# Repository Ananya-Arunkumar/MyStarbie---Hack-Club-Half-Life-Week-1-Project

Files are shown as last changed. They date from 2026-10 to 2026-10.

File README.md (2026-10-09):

**Starbie**

Starbie is a tiny desk buddy built using a Seeed XIAO ESP32-C3, an OLED display, and motion and temperature sensors.



PCB Editor View



3D view

**Features**
* Animated digital pet on a 0.96-inch OLED display
* Motion-controlled radial menu using an MPU6050 accelerometer
* Pet stats for joy, energy, and fullness
* Temperature and humidity readings using a DHT11 sensor
* Two buttons for interacting with the pet

**Hardware**
* Seeed XIAO ESP32-C3
* 0.96-inch SSD1306 OLED display
* MPU6050 accelerometer and gyroscope module (lets the thing know it's moving)
* DHT11 temperature and humidity sensor
* Two push buttons
* Starbie PCB

See BOM.csv for the bill of materials and PCB folder for the PCB design files.

**Software**
The PCB is designed using KiCad. The firmware is written for the Arduino IDE. (Refer firmware Folder)

**Building**
1. Gather the components listed in the bill of materials.
2. Assemble the circuit according to the schematic and wiring instructions.
3. Open the Starbie Arduino sketch in the Arduino IDE.
4. Install the required libraries.
5. Select the Seeed XIAO ESP32-C3 as the board.
6. Upload the sketch to the board.

Refer to the project guide for detailed assembly and setup instructions.

Project Files
Firmware/ — MyStarbie.ino
PCB/ — PCB layout, schematic, and KiCad project files
BOM.csv — Bill of materials

**Credits**
Starbie is based on the original project by SharKingStudios and Hack Club. Please refer to the original project repository and its license for attribution and reuse requirements.

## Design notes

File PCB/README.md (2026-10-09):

Starbie PCB Design Files

All of this is made through KiCad. Please download the necessary software and download the files for custom footprints and symbols.

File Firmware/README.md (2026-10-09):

**FIRMWARE**

The firmware is written for the Arduino IDE. Download the latest version of the Arduino IDE.

Below are some required libraries that I downloaded. You have to download these libraries in order for the firmware to work for this.
Required libraries:
Adafruit GFX Library
Adafruit SSD1306
Adafruit MPU6050
DHT sensor library

**Directions to install:**
1. Click _File_ --> _Preferences_ --> add the code below into the _Additional Board Managers URL_
* https://espressif.github.io/arduino-esp32/package_esp32_index.json
2. Select _Tools_ --> _Board_ --> _Board Manager_ --> search and download esp32 by Espressif Systems
3. Select _Tools_ --> _Board_ --> _esp32_ --> _XIAO_ESP32C3_ --> select the board's port under _Tools_ --> _Port_
4. Download the libraries above one by one (Click download all when asked about dependencies)
5. Open the Starbie.ino file and click Upload in the IDE

Under beginner settings is where I made my customizations. I changed the pet's starting stats, changed the bitmap pet, replaced the pet function on the radial menu with 'Shower', and gave it a star trail!

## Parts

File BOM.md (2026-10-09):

Starbie Kit - Provided by Hack Club

PCB - 9.90 + 9.33 shipping (JLCPCB)

Estimated total - $19.23

**Keep in mind, there is a BOM on the original Starbie repo which rounds to around 24.95 per kit but it is more expensive to buy that on your own since most of its components come in packs which cost more than listed**

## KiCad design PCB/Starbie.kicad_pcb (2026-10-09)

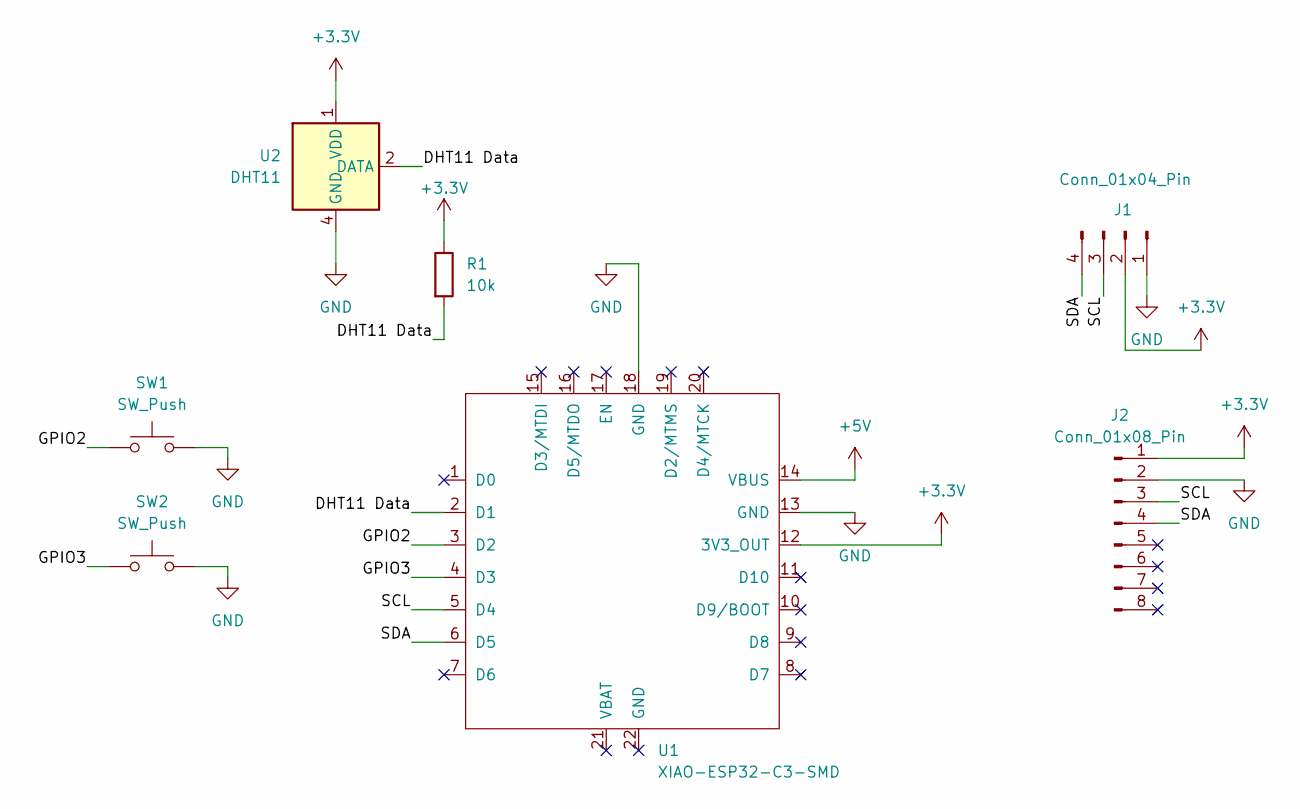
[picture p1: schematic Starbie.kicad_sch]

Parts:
J1: Conn_01x04_Pin; Display_128x64_096_I2C
J2: Conn_01x08_Pin; PinHeader_1x08_P2.54mm_Vertical
R1: 10k; R_Axial_DIN0204_L3.6mm_D1.6mm_P7.62mm_Horizontal
SW1, SW2: SW_Push; SW_Cherry_MX_1.00u_PCB
U1: XIAO-ESP32-C3-SMD
U2: DHT11; Aosong_DHT11_5.5x12.0_P2.54mm

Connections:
+3.3V: J1.2, J2.1, R1.1, U1.12 (3V3_OUT), U2.1 (VDD)
+5V: U1.14 (VBUS)
/DHT11 Data: R1.2, U1.2 (D1), U2.2 (DATA)
/GPIO2: SW1.1, U1.3 (D2)
/GPIO3: SW2.1, U1.4 (D3)
/SCL: J1.3, J2.3, U1.5 (D4)
/SDA: J1.4, J2.4, U1.6 (D5)
GND: J1.1, J2.2, SW1.2, SW2.2, U1.13 (GND), U1.18 (GND), U2.4 (GND)

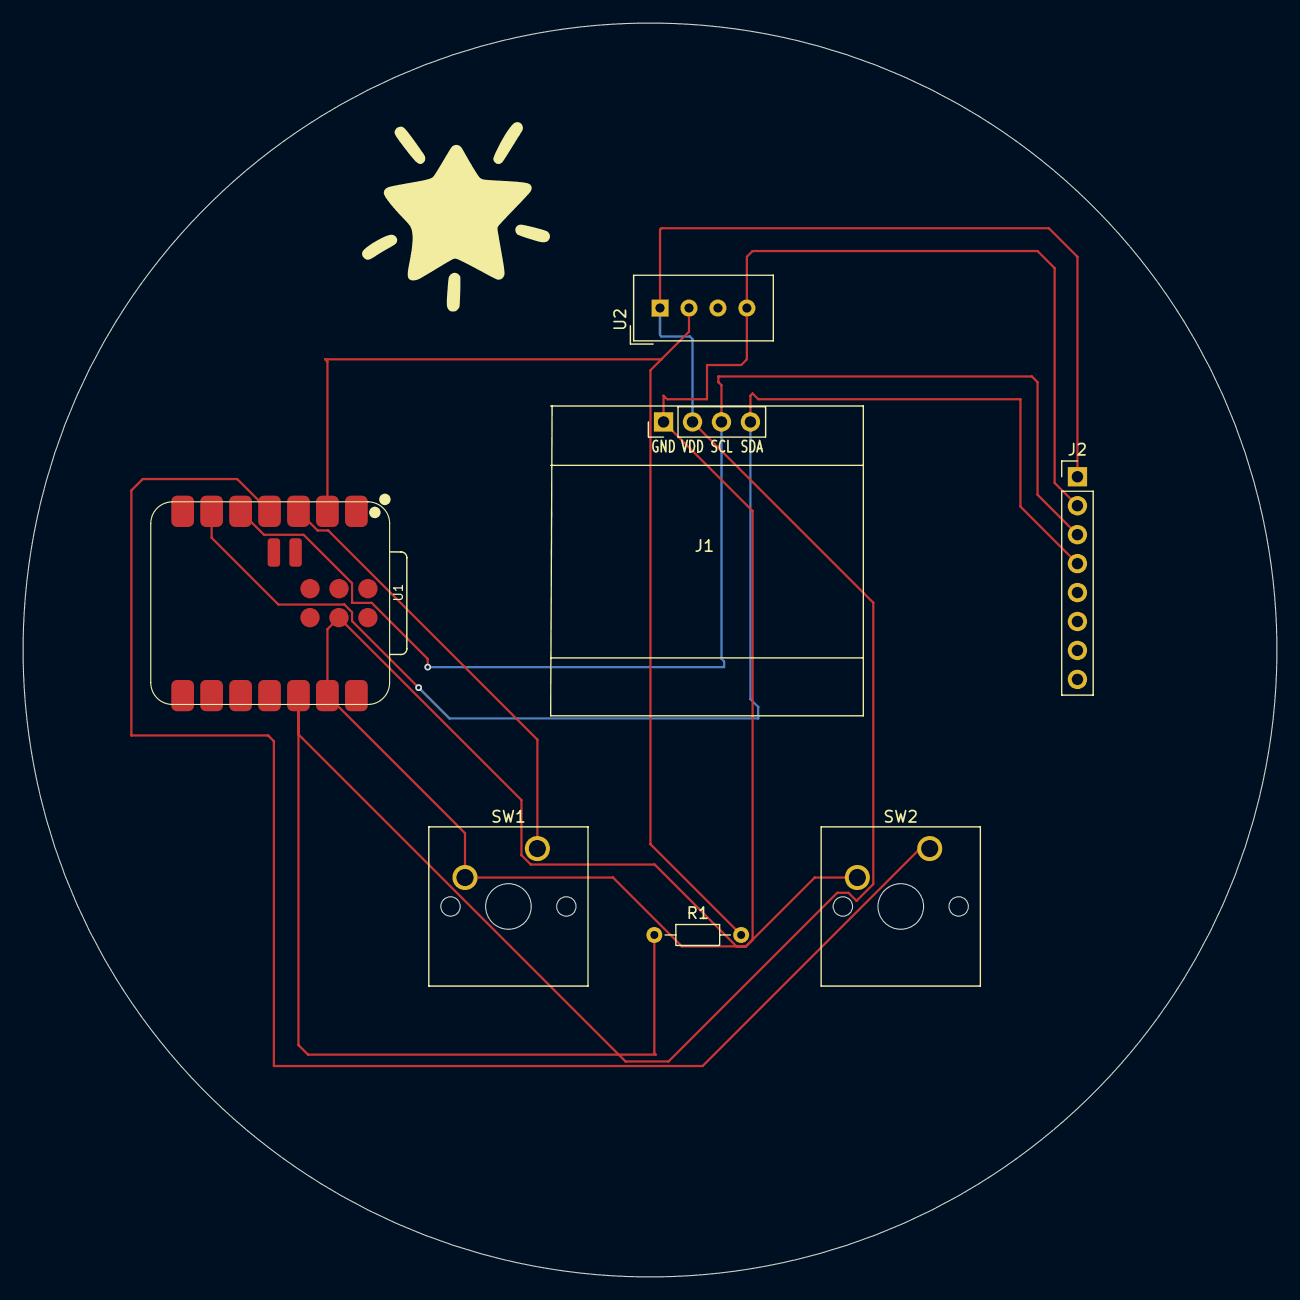
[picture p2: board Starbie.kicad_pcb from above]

Board: 2 copper layers, 110.0 x 110.0 mm, 7 parts (0 on the bottom side), 7 nets.

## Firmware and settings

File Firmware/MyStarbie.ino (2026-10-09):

/*
  Starbie: a tiny motion-controlled digital pet

  This is intentionally one file. Open this .ino file in Arduino IDE, edit
  the BEGINNER SETTINGS section, and upload it to a Seeed XIAO ESP32-C3.

  Install these libraries with Sketch > Include Library > Manage Libraries:
    - Adafruit GFX Library
    - Adafruit SSD1306
    - Adafruit MPU6050
    - DHT sensor library
  Arduino IDE will offer to install their dependencies too. Click Install All.
*/

#include <Wire.h>
#include <Adafruit_GFX.h>
#include <Adafruit_SSD1306.h>
#include <Adafruit_MPU6050.h>
#include <DHT.h>
#include <Preferences.h>
#include <math.h>

// =========================== BEGINNER SETTINGS ===========================
// Everything most builders will want to customize is in this one section.

// --- Your board's pins ----------------------------------------------------
// These are ESP32-C3 GPIO numbers, with the XIAO pin labels beside them.
const int I2C_SDA_PIN = 6;       // XIAO D4: OLED + MPU6050 SDA
const int I2C_SCL_PIN = 7;       // XIAO D5: OLED + MPU6050 SCL
const int DHT_PIN = 3;           // XIAO D1: DHT11 data
const int BUTTON_ONE_PIN = 4;    // XIAO D2: opens/confirms the radial menu
const int BUTTON_TWO_PIN = 5;    // XIAO D3: shows/hides stats

// Set this to false if your submission does not have a DHT11.
const bool USE_DHT11 = true;

// Most parts use these addresses. Only change them if an I2C scanner says
// your part is different (common OLED alternative: 0x3D).
const uint8_t OLED_ADDRESS = 0x3C;
const uint8_t MPU6050_ADDRESS = 0x68;

// --- Starting stats -------------------------------------------------------
// Stats are 0 to 100. They only change when you select an action or shake
// Starbie; nothing slowly drains while it sits on your desk.
const int STARTING_JOY = 80;
const int STARTING_ENERGY = 100;
const int STARTING_FULLNESS = 70;

// Set true, upload once, then set it back to false if you want a fresh pet.
const bool RESET_SAVED_PET_ON_BOOT = true;

// --- Radial menu ----------------------------------------------------------
// These four actions appear at TOP, RIGHT, BOTTOM, then LEFT in the menu.
// The last word controls the matching little visual reaction.
enum PetReaction {
  NAP_REACTION,
  JUMP_REACTION,
  HEART_REACTION,
  RUN_REACTION,
};

struct MenuItem {
  const char *label;
  int joyChange;
  int energyChange;
  int fullnessChange;
  PetReaction reaction;
};

const MenuItem MENU_ITEMS[] = {
  {"NAP",   1,  18, -4, NAP_REACTION},   // top: sleep and emit Zs
  {"PLAY", 12, -9, -5, RUN_REACTION},    // right: two fast laps + hearts
  {"FEED",  3,  2,  18, JUMP_REACTION},  // bottom: wiggle and jump
  {"SHOWER",   7,  -3,  -6, HEART_REACTION},  // left: jump and emit hearts
};
const int MENU_ITEM_COUNT = sizeof(MENU_ITEMS) / sizeof(MENU_ITEMS[0]);

// --- Movement feel --------------------------------------------------------
// Bigger MENU_TILT_LIMIT makes the menu ball move less.
const float MENU_TILT_LIMIT = 5.5f;

// MPU6050 orientation: change these settings instead of rewiring your board.
// 1. If the sensor is turned 90 degrees, set SWAP_MPU_AXES to true.
// 2. If a direction feels backwards, change that direction from 1.0f to -1.0f.
const bool SWAP_MPU_AXES = false;
const float MENU_X_DIRECTION = 1.0f;
const float MENU_Y_DIRECTION = -1.0f;

// A small dead zone makes the ball rest in the center until the board is tilted.
const float MENU_CENTER_DEADZONE = 0.8f;
const float SHAKE_THRESHOLD = 7.0f;

// Shake is the only movement that has an effect outside the radial menu.
const int SHAKE_JOY_CHANGE = 5;
const int SHAKE_ENERGY_CHANGE = -2;
const int SHAKE_FULLNESS_CHANGE = -1;

// --- Your pet's bitmap and animation -------------------------------------
// This is a simplified 32 by 32, one-bit version of the supplied character.
// You can replace it with your own art later; keep these size values matched
// to the sprite array you paste in.
const int PET_SPRITE_WIDTH = 32;
const int PET_SPRITE_HEIGHT = 32;

// The pet wanders unless it is asleep. A non-nap action does a tiny shake,
// then a jump, except PLAY which runs two fast laps.
const uint16_t PET_WALK_PIXEL_MS = 70;
const uint16_t PET_PRE_JUMP_MS = 230;
const uint16_t PET_JUMP_MS = 430;
const int PET_JUMP_HEIGHT = 16;
const uint32_t NAP_DURATION_MS = 48000;  // 48 seconds: four times the old nap.
const uint16_t HEARTS_DURATION_MS = 1600;
const uint16_t PLAY_LAP_MS = 800;
const uint8_t PLAY_LAP_COUNT = 2;

// Each byte stores eight pixels, left to right. This sparse outline keeps the
// supplied creature readable on a tiny, one-bit OLED: head, eye, legs, tail,
// and a small flower-like ear accent all stay separate instead of becoming a blob.
const uint8_t PROGMEM PET_SPRITE[] = {
	0x00, 0x00, 0x00, 0x00, 0x00, 0x00, 0x00, 0x00, 0x00, 0x00, 0x00, 0x00, 0x00, 0x00, 0x00, 0x00, 
	0x00, 0x00, 0x00, 0x00, 0x00, 0x01, 0x80, 0x00, 0x00, 0x02, 0x40, 0x00, 0x00, 0x02, 0x40, 0x00, 
	0x00, 0x02, 0x40, 0x00, 0x00, 0x04, 0x20, 0x00, 0x00, 0x04, 0x20, 0x00, 0x00, 0x04, 0x20, 0x00, 
	0x03, 0xf8, 0x1f, 0xc0, 0x02, 0x02, 0x40, 0x40, 0x02, 0x02, 0x40, 0x40, 0x01, 0x02, 0x40, 0x80, 
	0x00, 0x42, 0x42, 0x00, 0x00, 0x20, 0x04, 0x00, 0x00, 0x20, 0x04, 0x00, 0x00, 0x40, 0x02, 0x00, 
	0x00, 0x40, 0x02, 0x00, 0x00, 0x00, 0x00, 0x00, 0x01, 0x81, 0x81, 0x80, 0x01, 0x86, 0x61, 0x80, 
	0x02, 0x38, 0x1c, 0x40, 0x03, 0x30, 0x0c, 0xc0, 0x03, 0xc0, 0x03, 0xc0, 0x00, 0x00, 0x00, 0x00, 
	0x00, 0x00, 0x00, 0x00, 0x00, 0x00, 0x00, 0x00, 0x00, 0x00, 0x00, 0x00, 0x00, 0x00, 0x00, 0x00,
};
// ===========================================================================
// You can read below without needing to understand every line. The rest of
// the sketch handles buttons, sensors, drawing, and saving automatically.

const int SCREEN_WIDTH = 128;
const int SCREEN_HEIGHT = 64;
const int MENU_CENTER_X = 64;
const int MENU_CENTER_Y = 32;
const int MENU_ITEM_X[] = {64, 108, 64, 20};
const int MENU_ITEM_Y[] = {12, 32, 53, 32};
const int MENU_BALL_X_RANGE = 37;
const int MENU_BALL_Y_RANGE = 22;
const uint16_t BUTTON_DEBOUNCE_MS = 30;
const uint16_t MPU_READ_INTERVAL_MS = 30;
const uint16_t DHT_READ_INTERVAL_MS = 2200;
const uint16_t SHAKE_COOLDOWN_MS = 650;
const float STANDARD_GRAVITY = 9.80665f;

Adafruit_SSD1306 display(SCREEN_WIDTH, SCREEN_HEIGHT, &Wire, -1);
Adafruit_MPU6050 mpu;
DHT dht(DHT_PIN, DHT11);
Preferences preferences;

struct PetState {
  int joy;
  int energy;
  int fullness;
};

struct ButtonState {
  int pin;
  bool stableState;
  bool lastRawState;
  uint32_t lastChangedAt;
};

enum View {
  PET_VIEW,
  MENU_VIEW,
  STATS_VIEW,
};

PetState pet = {STARTING_JOY, STARTING_ENERGY, STARTING_FULLNESS};
ButtonState buttonOne = {BUTTON_ONE_PIN, HIGH, HIGH, 0};
ButtonState buttonTwo = {BUTTON_TWO_PIN, HIGH, HIGH, 0};
View currentView = PET_VIEW;

bool mpuFound = false;
bool dhtFound = false;
float accelerationX = 0.0f;
float accelerationY = 0.0f;
float accelerationZ = STANDARD_GRAVITY;
float temperatureC = NAN;
float humidity = NAN;
float menuBallX = MENU_CENTER_X;
float menuBallY = MENU_CENTER_Y;
float menuCenterAccelerationX = 0.0f;
float menuCenterAccelerationY = 0.0f;
int selectedMenuItem = -1;
uint32_t lastMpuReadAt = 0;
uint32_t lastDhtReadAt = 0;
uint32_t lastShakeAt = 0;
uint32_t shakeAnimationEndsAt = 0;
uint32_t petJumpStartedAt = 0;
uint32_t nappingUntil = 0;
uint32_t heartAnimationEndsAt = 0;
uint32_t playRunStartedAt = 0;
int nappingPetX = 0;

int petWalkingX(uint32_t now);

int keepInRange(int value, int smallest, int largest) {
  return constrain(value, smallest, largest);
}

void changePet(int joyChange, int energyChange, int fullnessChange) {
  pet.joy = keepInRange(pet.joy + joyChange, 0, 100);
  pet.energy = keepInRange(pet.energy + energyChange, 0, 100);
  pet.fullness = keepInRange(pet.fullness + fullnessChange, 0, 100);
}

void loadPet() {
  preferences.begin("starbie", false);
  if (RESET_SAVED_PET_ON_BOOT) {
    preferences.clear();
  }
  pet.joy = preferences.getInt("joy", STARTING_JOY);
  pet.energy = preferences.getInt("energy", STARTING_ENERGY);
  pet.fullness = preferences.getInt("full", STARTING_FULLNESS);
}

void savePet() {
  preferences.putInt("joy", pet.joy);
  preferences.putInt("energy", pet.energy);
  preferences.putInt("full", pet.fullness);
}

void setUpButton(ButtonState &button) {
  pinMode(button.pin, INPUT_PULLUP);
  button.stableState = digitalRead(button.pin);
  button.lastRawState = button.stableState;
  button.lastChangedAt = millis();
}

// Returns true exactly once for each press, even if the switch bounces.
bool wasPressed(ButtonState &button) {
  const bool rawState = digitalRead(button.pin);
  const uint32_t now = millis();

  if (rawState != button.lastRawState) {
    button.lastRawState = rawState;
    button.lastChangedAt = now;
  }

  if (rawState != button.stableState &&
      now - button.lastChangedAt >= BUTTON_DEBOUNCE_MS) {
    button.stableState = rawState;
    return button.stableState == LOW;
  }

  return false;
}

void updateMpu() {
  if (!mpuFound || millis() - lastMpuReadAt < MPU_READ_INTERVAL_MS) {
    return;
  }
  lastMpuReadAt = millis();

  sensors_event_t acceleration;
  sensors_event_t gyro;
  sensors_event_t sensorTemperature;
  mpu.getEvent(&acceleration, &gyro, &sensorTemperature);
  accelerationX = acceleration.acceleration.x;
  accelerationY = acceleration.acceleration.y;
  accelerationZ = acceleration.acceleration.z;
}

void updateDht() {
  if (!dhtFound || millis() - lastDhtReadAt < DHT_READ_INTERVAL_MS) {
    return;
  }
  lastDhtReadAt = millis();

  const float newHumidity = dht.readHumidity();
  const float newTemperatureC = dht.readTemperature();
  if (!isnan(newHumidity)) {
    humidity = newHumidity;
  }
  if (!isnan(newTemperatureC)) {
    temperatureC = newTemperatureC;
  }
}

int petWalkingX(uint32_t now) {
  const int farthestX = SCREEN_WIDTH - PET_SPRITE_WIDTH;
  const uint32_t roundTrip = static_cast<uint32_t>(farthestX) * 2;
  const uint32_t step = (now / PET_WALK_PIXEL_MS) % roundTrip;
  return step <= farthestX ? step : roundTrip - step;
}

uint32_t playRunDuration() {
  return static_cast<uint32_t>(PLAY_LAP_MS) * PLAY_LAP_COUNT;
}

bool isNapping() {
  return nappingUntil != 0 && millis() < nappingUntil;
}

bool isPlaying() {
  return playRunStartedAt != 0 && millis() - playRunStartedAt < playRunDuration();
}

int playRunX(uint32_t now) {
  const int farthestX = SCREEN_WIDTH - PET_SPRITE_WIDTH;
  const uint32_t lapAge = (now - playRunStartedAt) % PLAY_LAP_MS;
  const float progress = static_cast<float>(lapAge) / PLAY_LAP_MS;
  return progress < 0.5f ? static_cast<int>(progress * 2.0f * farthestX)
                         : static_cast<int>((1.0f - progress) * 2.0f * farthestX);
}

void updatePetTimers() {
  if (nappingUntil != 0 && !isNapping()) {
    nappingUntil = 0;  // The pet wakes naturally when its nap time is over.
  }
  if (playRunStartedAt != 0 && !isPlaying()) {
    playRunStartedAt = 0;  // PLAY is exactly two left-to-right-to-left laps.
  }
}

// While the menu is open, the MPU6050 acts like a tiny air mouse. The position
// at the instant Button 1 opens the menu becomes the center for that menu use.
void updateMenuBall() {
  float xTilt = accelerationX - menuCenterAccelerationX;
  float yTilt = accelerationY - menuCenterAccelerationY;

  if (SWAP_MPU_AXES) {
    const float oldXTilt = xTilt;
    xTilt = yTilt;
    yTilt = oldXTilt;
  }
  xTilt = constrain(xTilt * MENU_X_DIRECTION, -MENU_TILT_LIMIT, MENU_TILT_LIMIT);
  yTilt = constrain(yTilt * MENU_Y_DIRECTION, -MENU_TILT_LIMIT, MENU_TILT_LIMIT);
  const float targetX = MENU_CENTER_X + (xTilt / MENU_TILT_LIMIT) * MENU_BALL_X_RANGE;
  const float targetY = MENU_CENTER_Y + (yTilt / MENU_TILT_LIMIT) * MENU_BALL_Y_RANGE;

  // This small amount of smoothing makes the ball feel less jittery.
  menuBallX += (targetX - menuBallX) * 0.20f;
  menuBallY += (targetY - menuBallY) * 0.20f;

  // The menu has four full sectors, not four tiny targets. Any tilt direction
  // past the center dead zone selects its matching top/right/bottom/left action.
  if (fabsf(xTilt) < MENU_CENTER_DEADZONE && fabsf(yTilt) < MENU_CENTER_DEADZONE) {
    selectedMenuItem = -1;
  } else if (fabsf(xTilt) > fabsf(yTilt)) {
    selectedMenuItem = xTilt > 0.0f ? 1 : 3;  // right or left
  } else {
    selectedMenuItem = yTilt > 0.0f ? 2 : 0;  // bottom or top
  }
}

void checkForShake() {
  if (!mpuFound || currentView != PET_VIEW) {
    return;
  }

  const float magnitude = sqrtf(accelerationX * accelerationX +
                                accelerationY * accelerationY +
                                accelerationZ * accelerationZ);
  const uint32_t now = millis();
  if (fabsf(magnitude - STANDARD_GRAVITY) >= SHAKE_THRESHOLD &&
      now - lastShakeAt >= SHAKE_COOLDOWN_MS) {
    lastShakeAt = now;
    nappingUntil = 0;  // A shake wakes a sleeping pet right away.
    shakeAnimationEndsAt = now + 350;
    changePet(SHAKE_JOY_CHANGE, SHAKE_ENERGY_CHANGE, SHAKE_FULLNESS_CHANGE);
    savePet();
  }
}

void openMenu() {
  currentView = MENU_VIEW;
  selectedMenuItem = -1;
  menuBallX = MENU_CENTER_X;
  menuBallY = MENU_CENTER_Y;
  // Calibrate here so every menu starts from however the builder is holding it.
  menuCenterAccelerationX = accelerationX;
  menuCenterAccelerationY = accelerationY;
}

void chooseMenuItem() {
  if (selectedMenuItem == -1) {
    return;  // Keep the menu open until the ball reaches a choice.
  }

  const MenuItem &item = MENU_ITEMS[selectedMenuItem];
  changePet(item.joyChange, item.energyChange, item.fullnessChange);
  savePet();
  const uint32_t now = millis();
  nappingUntil = 0;
  heartAnimationEndsAt = 0;
  playRunStartedAt = 0;

  if (item.reaction == NAP_REACTION) {
    petJumpStartedAt = 0;
    nappingPetX = petWalkingX(now);
    nappingUntil = now + NAP_DURATION_MS;
  } else if (item.reaction == RUN_REACTION) {
    petJumpStartedAt = 0;
    playRunStartedAt = now;
    heartAnimationEndsAt = now + playRunDuration();
  } else {
    // A confirmed action gets a little anticipation shake before the jump.
    petJumpStartedAt = now;
    if (item.reaction == HEART_REACTION) {
      heartAnimationEndsAt = now + HEARTS_DURATION_MS;
    }
  }
  currentView = PET_VIEW;
}

void handleButtons() {
  if (wasPressed(buttonOne)) {
    if (currentView == MENU_VIEW) {
      chooseMenuItem();
    } else {
      openMenu();
    }
  }

  if (wasPressed(buttonTwo)) {
    // Button 2 never changes the pet. It only lets you peek at the values.
    currentView = currentView == STATS_VIEW ? PET_VIEW : STATS_VIEW;
  }
}

void drawStar(int x, int y) {
  display.drawPixel(x - 1, y - 2, SSD1306_WHITE);
  display.drawPixel(x - 0.7, y - 1, SSD1306_WHITE);
  display.drawPixel(x, y - 1.5, SSD1306_WHITE);
  display.drawPixel(x + 1, y - 2, SSD1306_WHITE);
  display.drawPixel(x + 0.7, y - 1, SSD1306_WHITE);
  display.drawPixel(x - 1.5, y - 0.7, SSD1306_WHITE);
  display.drawPixel(x - 0.5, y - 0.2, SSD1306_WHITE);
  display.drawPixel(x + 1.5, y - 0.7, SSD1306_WHITE);
  display.drawPixel(x + 0.5, y - 0.2, SSD1306_WHITE);
  display.drawPixel(x, y + 0.5, SSD1306_WHITE);
}

void drawHeart(int x, int y) {
  // A tiny seven-pixel-wide heart that stays crisp on the OLED.
  display.fillRect(x - 2, y, 2, 2, SSD1306_WHITE);
  display.fillRect(x + 1, y, 2, 2, SSD1306_WHITE);
  display.fillRect(x - 3, y + 2, 7, 2, SSD1306_WHITE);
  display.fillRect(x - 2, y + 4, 5, 1, SSD1306_WHITE);
  display.fillRect(x - 1, y + 5, 3, 1, SSD1306_WHITE);
  display.drawPixel(x, y + 6, SSD1306_WHITE);
}

void drawHearts(uint32_t now, int petX, int petY) {
  if (now >= heartAnimationEndsAt) {
    return;
  }

  const float progress =
      1.0f - static_cast<float>(heartAnimationEndsAt - now) / HEARTS_DURATION_MS;
  const int rise = static_cast<int>(progress * 18.0f);
  drawHeart(petX + 10, petY - 3 - rise);
  drawHeart(petX + 22, petY - 9 - rise / 2);
}

void drawSleepZs(uint32_t now, int petX, int petY) {
  // The Zs float upward, then loop back down while the pet is napping.
  const int rise = static_cast<int>((now / 300UL) % 15UL);
  display.setTextSize(1);
  display.setTextColor(SSD1306_WHITE);
  display.setCursor(petX + 23, petY - 2 - rise);
  display.print("z");
  display.setCursor(petX + 28, petY - 8 - rise / 2);
  display.print("z");
}

void drawPet() {
  display.clearDisplay();

  const uint32_t now = millis();
  int petX = isNapping() ? nappingPetX : petWalkingX(now);
  if (isPlaying()) {
    petX = playRunX(now);
  }
  int petY = SCREEN_HEIGHT - PET_SPRITE_HEIGHT;

  // The pet always wanders except during a nap; PLAY temporarily takes over.
  if (now < shakeAnimationEndsAt) {
    petX += static_cast<int>(sinf(now / 18.0f) * 3.0f);
  }

  if (!isNapping() && petJumpStartedAt != 0) {
    const uint32_t animationAge = now - petJumpStartedAt;

    if (animationAge < PET_PRE_JUMP_MS) {
      petX += static_cast<int>(sinf(now / 16.0f) * 3.0f);
    } else if (animationAge < PET_PRE_JUMP_MS + PET_JUMP_MS) {
      const float jumpProgress =
          static_cast<float>(animationAge - PET_PRE_JUMP_MS) / PET_JUMP_MS;
      petY -= static_cast<int>(sinf(jumpProgress * PI) * PET_JUMP_HEIGHT);
    } else {
      petJumpStartedAt = 0;
    }
  }

  petX = constrain(petX, 0, SCREEN_WIDTH - PET_SPRITE_WIDTH);
  display.drawBitmap(petX, petY, PET_SPRITE, PET_SPRITE_WIDTH, PET_SPRITE_HEIGHT,
                     SSD1306_WHITE);

  if (!isNapping() && (now / 250) % 2 == 0) {
  drawStar(petX - 4, petY + 18);
  }
  if (isNapping()) {
    drawSleepZs(now, petX, petY);
  }
  drawHearts(now, petX, petY);
}

void drawMenuItem(int item) {
  const int boxWidth = 33;
  const int boxHeight = 12;
  const int boxX = MENU_ITEM_X[item] - boxWidth / 2;
  const int boxY = MENU_ITEM_Y[item] - boxHeight / 2;
  const bool isSelected = item == selectedMenuItem;

  if (isSelected) {
    display.fillRoundRect(boxX, boxY, boxWidth, boxHeight, 3, SSD1306_WHITE);
    display.setTextColor(SSD1306_BLACK);
  } else {
    display.drawRoundRect(boxX, boxY, boxWidth, boxHeight, 3, SSD1306_WHITE);
    display.setTextColor(SSD1306_WHITE);
  }

  display.setTextSize(1);
  const int labelLength = strlen(MENU_ITEMS[item].label);
  display.setCursor(MENU_ITEM_X[item] - labelLength * 3, MENU_ITEM_Y[item] - 3);
  display.print(MENU_ITEMS[item].label);
  display.setTextColor(SSD1306_WHITE);
}

void drawMenu() {
  display.clearDisplay();
  // The two diagonal lines divide the screen into four big selection sectors.
  display.drawLine(0, 0, SCREEN_WIDTH - 1, SCREEN_HEIGHT - 1, SSD1306_WHITE);
  display.drawLine(0, SCREEN_HEIGHT - 1, SCREEN_WIDTH - 1, 0, SSD1306_WHITE);
  for (int item = 0; item < MENU_ITEM_COUNT; item++) {
    drawMenuItem(item);
  }

  display.drawCircle(MENU_CENTER_X, MENU_CENTER_Y, 11, SSD1306_WHITE);
  display.fillCircle(static_cast<int>(menuBallX), static_cast<int>(menuBallY), 4,
                     SSD1306_WHITE);
}

void drawStatBar(int y, const char *label, int value) {
  display.setTextSize(1);
  display.setTextColor(SSD1306_WHITE);
  display.setCursor(4, y);
  display.print(label);
  display.drawRect(48, y, 57, 8, SSD1306_WHITE);
  display.fillRect(49, y + 1, map(value, 0, 100, 0, 55), 6, SSD1306_WHITE);
  display.setCursor(109, y);
  display.print(value);
}

void drawStats() {
  display.clearDisplay();
  drawStatBar(5, "JOY", pet.joy);
  drawStatBar(20, "ENERGY", pet.energy);
  drawStatBar(35, "FULL", pet.fullness);

  display.setCursor(4, 53);
  if (!isnan(temperatureC)) {
    display.print("TEMP ");
    display.print(static_cast<int>(temperatureC));
    display.print("C");
  } else {
    display.print("TEMP --");
  }

  display.setCursor(76, 53);
  if (!isnan(humidity)) {
    display.print("H ");
    display.print(static_cast<int>(humidity));
    display.print("%");
  } else {
    display.print("H --");
  }
}

void drawCurrentView() {
  if (currentView == MENU_VIEW) {
    drawMenu();
  } else if (currentView == STATS_VIEW) {
    drawStats();
  } else {
    drawPet();
  }
  display.display();
}

void setup() {
  Serial.begin(115200);
  Wire.begin(I2C_SDA_PIN, I2C_SCL_PIN);
  setUpButton(buttonOne);
  setUpButton(buttonTwo);
  loadPet();

  if (!display.begin(SSD1306_SWITCHCAPVCC, OLED_ADDRESS)) {
    Serial.println("OLED not found. Check power, GND, SDA, SCL, and address.");
    while (true) {
      delay(10);
    }
  }

  mpuFound = mpu.begin(MPU6050_ADDRESS, &Wire);
  if (mpuFound) {
    mpu.setAccelerometerRange(MPU6050_RANGE_8_G);
    mpu.setGyroRange(MPU6050_RANGE_500_DEG);
    mpu.setFilterBandwidth(MPU6050_BAND_21_HZ);
  } else {
    Serial.println("MPU6050 not found. The menu will not move until it is connected.");
  }

  if (USE_DHT11) {
    dht.begin();
    dhtFound = true;
  }

  drawCurrentView();
}

void loop() {
  updateMpu();
  updateDht();
  updatePetTimers();
  handleButtons();

  if (currentView == MENU_VIEW) {
    updateMenuBall();
  } else {
    checkForShake();
  }

  drawCurrentView();
  delay(16);  // Smooth display updates without making the code complicated.
}

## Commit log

2026-10-09 Update README with KiCad software instructions
    Added additional information about KiCad software requirements.
2026-10-09 Revise BOM with cost breakdown and notes
    Updated BOM with additional details and estimated total.
2026-10-09 Enhance README with images and additional views
    Added images and PCB/3D view sections to README.
2026-10-16 Added a BOM.csv file and deleted BOM.md
2026-10-16 Update BOM.csv with new components and total
    Added '10k Resistor' entry and 'Total' row to BOM.
2026-10-17 Added Gerbers.zip to its own folder
2026-10-30 Update README with new images and PCB view
    Added additional images and PCB editor view to README.
